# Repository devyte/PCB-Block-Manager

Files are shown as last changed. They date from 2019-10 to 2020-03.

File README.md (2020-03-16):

# Block Manager 
### Hardware Files For The Block Manager Board
These are the printed circuit board (PCB) files, CAD files, specification sheets and all technical drawings needed to make the DKblock Block Manager board. There are two boards that make a minimum DK system, a Block Manager PCB and a Pack Supervisor PCB (with software changes to the 20 client version provided). Note that the bill of materials (BOM) and other technical documents can be opened in [OpenOffice](https://www.openoffice.org) format and PCB files are in [EAGLE](https://www.autodesk.com/products/eagle/overview) format but they can also be opened and edited in the open source Kicad program.
One version is provided, that is Rev D which is a fully tested board.

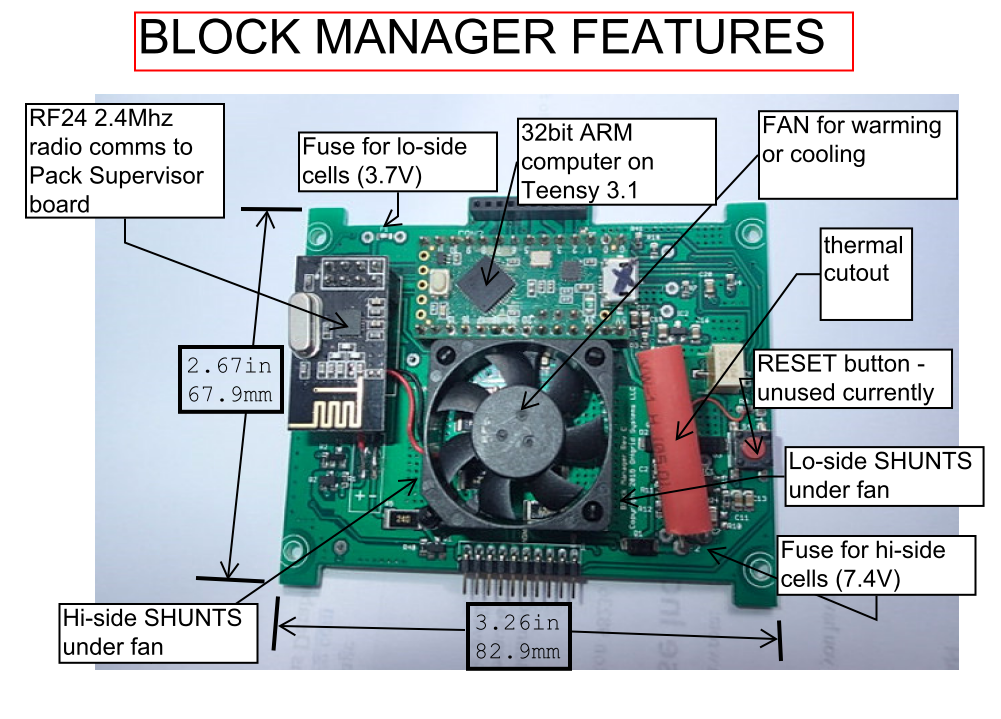
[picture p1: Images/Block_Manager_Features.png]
Block Manager Features


Block Manager Front RevD

Block Manager Back RevD

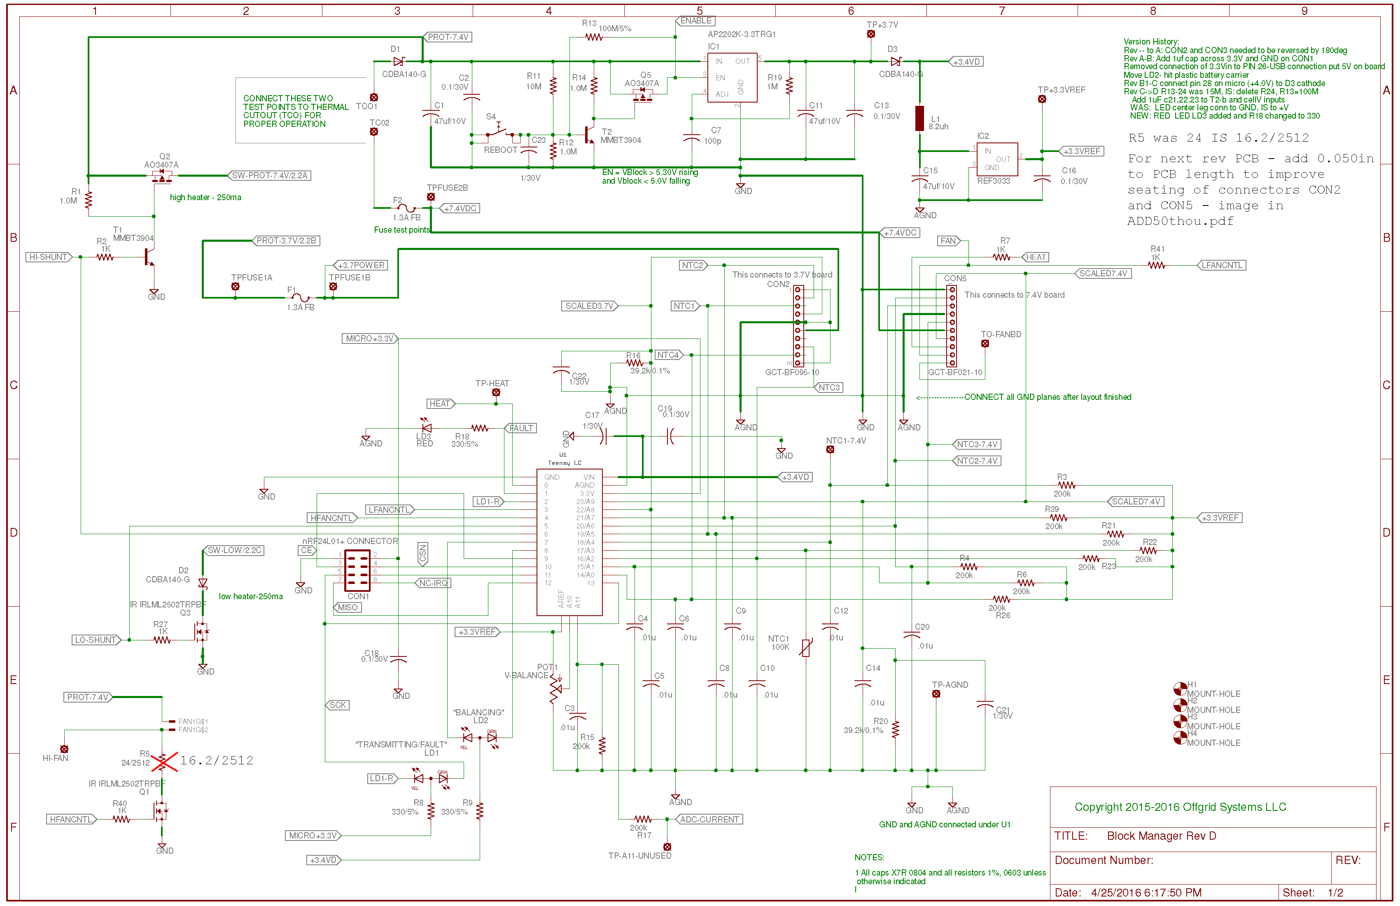
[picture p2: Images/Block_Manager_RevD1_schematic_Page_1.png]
Block Manager Schematic RevD1 Page 1


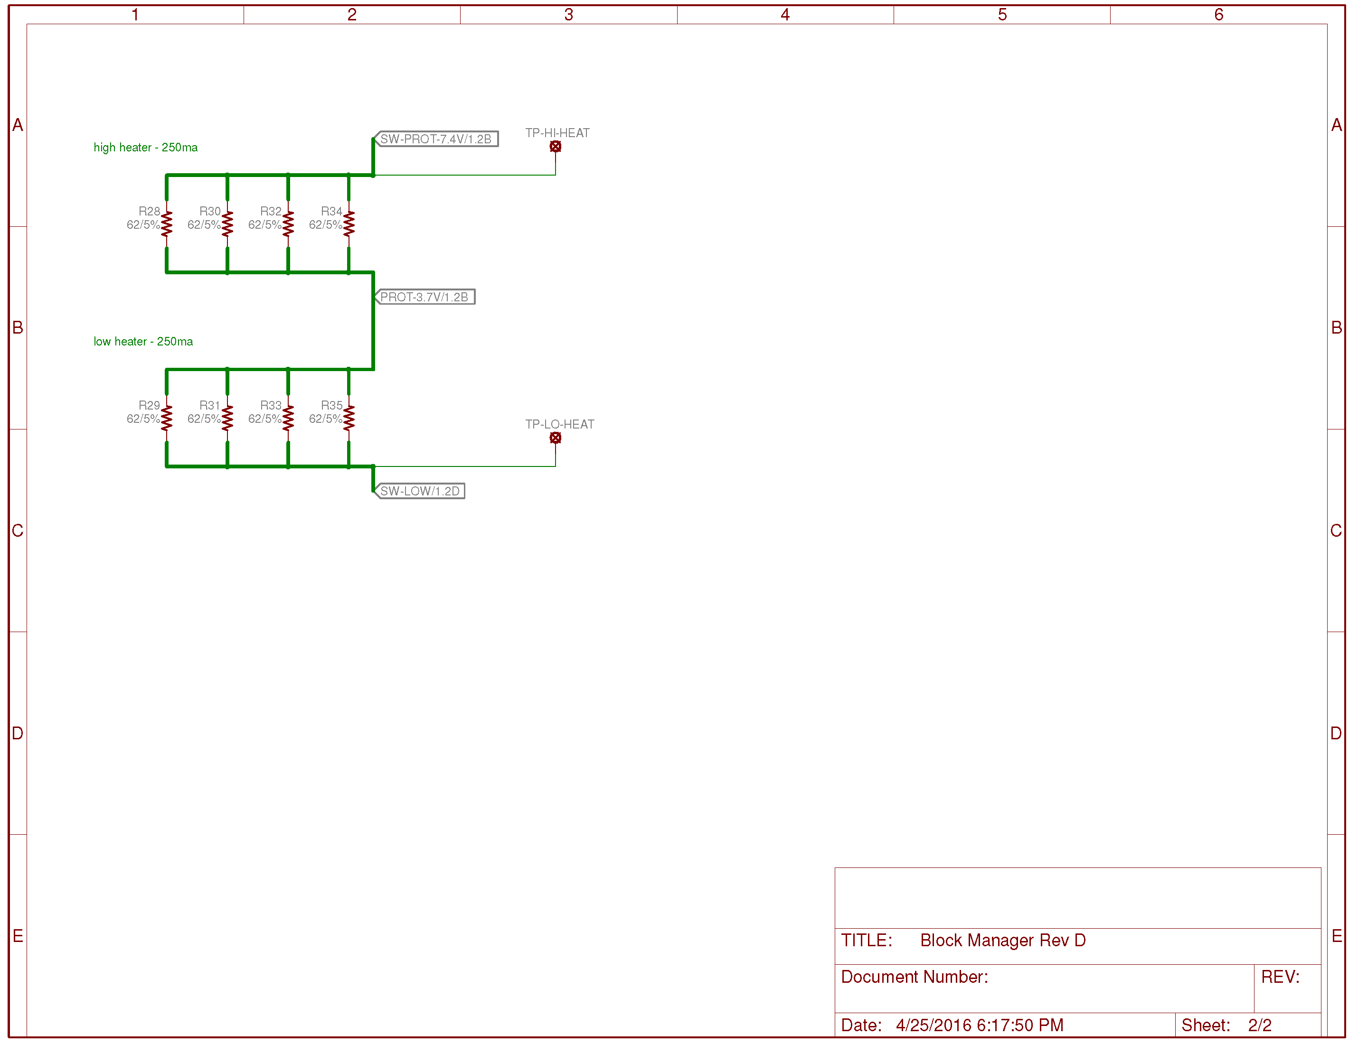
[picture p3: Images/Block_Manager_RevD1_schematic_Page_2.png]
Block Manager Schematic RevD1 Page 2


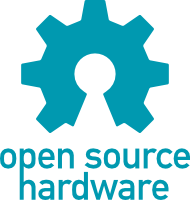
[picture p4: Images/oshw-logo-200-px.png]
Open Hardware


All DKblock software and hardware is released as open source hardware (OSHW) as defined by the OSHWA: https://www.oshwa.org/definition/ and under the JSON license defined at https://www.json.org/license.html

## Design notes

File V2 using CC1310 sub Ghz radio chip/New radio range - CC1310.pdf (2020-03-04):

Sheet1

Page 1

## New radio range – cc1310 using two CC1310 Lauchpads and TI SmartRF studio

Test conditions, Cow hill lab, TX/RX set at 50kbps, 2-GFSK, 25kHz deviation for most of testing, also tested at 500kBps,

### 175khz dev with no real changes, both CC1310 Lauchpad units had low cost PCB antenna

Freq (Mhz) TX power dBm RX @1 meter range(dBm) 9 meter range | notes
750 | 14 | -32 | -52 | all RX is at 0.0% PER and 0.00% Bit error rate and tested at 50k-500kBPS no discernable receive signal loss
850 -20
868 | | -20 | -49
950 -32
1000 | | -39 | -70 | Would go from -70 to -80 by just walking around room between TX and RX units
1100 -50
868 | -10 | | -72
868 OFF | | | -93

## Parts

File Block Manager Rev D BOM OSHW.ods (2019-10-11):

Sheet: Sheet1
Block Manager BOM |  | Last edited: | 10/10/19 | For building | Rev D PCB
Qty | Value | Device | Package | Parts | Description | 1KPRICE | 100PCPRICE | extended 1k | LOPROFILE-PINHEADER | LOPROFILE-SOCKET | MPN | Alternative PN |  | website
1 | LED | Red SMT LED | 0603 – side looking | LD3 | LED, 0603 RED clear 0603 RA SMD | 0.0488 | 0.112 | 0.0488 |  |  | Lite-On LTST-S270KRKT | Any RA Red 50mcd 0603 SMT LED
2 | LED | Yellow Green SMT LED | 3x2x1mm – side looking | LD2, LD1 | LED 3.0X1.0MM Y/G WTR CLR RA SMD | 0.10951 | 0.2 | 0.21902 |  |  | Kingbright APBA3010SYKCGKC-GX
10 | .01uf | C-USC0805 | TIMS_INDUCTOR_C0805 | C3, C4, C5, C6, C8, C9, C10, C12, c14, C20 | CAP CER 10000PF 50V 10% X7R 0805 | 0.008 | 0.015 | 0.08 |  |  | Kemet C0805C103K5RACTU
5 | 0.1uf | C-USC0805 | TIMS_INDUCTOR_C0805 | C2, C13, C16, C18, C19 | CAP CER 0.1UF 50V 10% X7R 0805 | 0.012 | 0.022 | 0.06 |  |  | Kemet C0805C104K5RACTU
4 | 1uf | USC0805 | C0805 | C17, C21, C22, C23 | CAP CER 1UF 50V 10% X7R 0805 | 0.08 | 0.14 | 0.32 |  |  | Kemet C0805C105K5RACTU
1 | 100p | C-USC0805 | TIMS_INDUCTOR_C0805 | C7 | CAP CER 100PF 50V 10% X7R 0805 | 0.048 | 0.08 | 0.048 |  |  | Kemet C0805C101K5RACTU
3 | 47uf/10V | C-USC0805K | C0805K | C11, C1, C15 | CAP CER 47UF 10V 20% X5R 0805 | 0.271 | 0.39 | 0.813 |  |  | Samsung CL21A476MRYNNNE | Murata GRM21BR61A476ME15L
2 | 1.3A FB | Fuse | F0603 | F1, F2 | FUSE BOARD MOUNT 1.3A 32VDC 0603 | 0.134 | 0.2 | 0.268 |  |  | TE 0603SFV125F/32-2
1 | 100K | NTC-MURATA-NCP18WF104J03RB | 603 | NTC1 | THERMISTOR NTC 100K OHM 5% 0603 | 0.07999 | 0.106 | 0.07999 |  |  | MURATA NCP18WF104J03RB
3 | 1.0M | R-US_R0603 | R0603 | R1, R12, R14 | RES SMD 1M OHM 1% 1/10W 0603 | 0.0084 | 0.0187 | 0.0252 |  |  | Bourns CR0603-FX-1004ELF
1 | 10M | R-US_R0603 | R0603 | R11 | RES SMD 10M OHM 5% 1/10W 0603 | 0.00525 | 0.0117 | 0.00525 |  |  | Bourns CR0603-JW-106ELF
1 | 100k pot | potentiometer | 7x7x7mm | POT1 | Potentiometer, 100k right angle, .5W SMD | 0.74 | 0.91 | 0.74 |  |  | Bourns 3361S-1-104GLF
5 | 1K | R-US_R0603 | R0603 | R2, R7, R27, R40, R41 | RES SMD 1K OHM 1% 1/10W 0603 | 0.0084 | 0.018 | 0.042 |  |  | Bourns CR0603-FX-1001ELF
1 | 100M | R-US_R0603 | R0603 | R13 | RES SMD 100M OHM 5% 1/10W 0603 | 0.0704 | 0.12 | 0.0704 |  |  | Stackpole HMC0603JT100M | any thick film 100M 5% resistor 0603
1 | 2.2M | R-US_R0603 | R0603 | R19 | RESISTOR, American symbol | 0.0041 | 0.1 | 0.0041 |  |  | Panasonic ERJ-3EKF2204V
10 | 200k | R-US_R0603 | R0603 | R3, R4, R6, R15, R17, R21, R22, R23, R26,R39 | RESISTOR, American symbol | 0.07 | 0.18 | 0.7 |  |  | Bourns CR0603-FX-2003ELF
1 | 24/2512 | R-US_R2512 | R2512 | R5 | RES SMD 24 OHM 5% 1W 2512 | 0.05 | 0.12 | 0.05 |  |  | Rohm MCR100JZHJ240
3 | 330/5% | R-US_R0603 | R0603 | R8. R9, R18 | RES SMD 330 OHM 5% 1/10W 0603 | 0.005 | 0.011 | 0.015 |  |  | Bourns CR0603-JW-331ELF
2 | 39.2K/ 0.1% | R-US_R0603 | R0603 | R16, R20 | RES SMD 39.2KOHM 0.1% 1/10W 0603 | 0.079 | 0.162 |  |  |  | Susumi RG1608P-3922-B-T5
8 | 62/5% | R-US_R2512 | R2512 | R28, R29, R30, R31, R32, R33, R34, R35 | RES SMD 62 OHM 5% 1W 2512 | 0.05 | 0.12 | 0.4 |  |  | Rohm MCR100JZHJ620
1 | 8.2uh | SM-1206 | SM-1206 | L1 | FIXED IND 8.2UH 25MA 800 MOHM | 0.1 | 0.136 | 0.1 |  |  | Abracon AIML-1206-8R2K-T
2 | AO3407A | AO3407A | SOT23-BIGPADS | Q2.Q5 | MOSFET P-CH 30V 4.3A SOT23 | 0.092 | 0.203 | 0.184 |  |  | Alpha AO3407A
1 | AP2202K-3.3TRG1 | MIC5205 | SOT23-5 | IC1 | VOLTAGE REGULATOR | 0.103 | 0.23 | 0.103 |  |  | Diodes AP2202K-3.3TRG1
1 | REF3033 | REF3033 | SOT23 | IC2 | IC VREF SERIES 3.3V SOT23-3 | 0.675 | 1.25 | 0.675 |  |  | TI REF3033AIDBZR
3 | CDBA140-G | CDBA140-G | DO214AC | D1, D2, D3 | DIODE SCHOTTKY 40V 1A DO214AC | 0.068 | 0.187 | 0.204 |  |  | Comchip CDBA140-G
2 | IRLML2502TRPBF | IRLML2060TRPBF | SOT23 | Q1, Q3 | MOSFET N-CH 60V 1.2A SOT23-3 | 0.11 | 0.144 | 0.22 |  |  | IR IRLML2502TRPBF
2 | MMBT3904 | MMBT3904LT1-NPN-SOT23-BEC | SOT23-BEC | T1, T2 | TRANS NPN 40V 0.2A SOT2 | 0.02 | 0.062 | 0.04 |  |  | NXP MMBT3904,215
1 | 10 pin socket | Female single inline socket | 1 row x 10 positions | CON2 | 2.0 mm socket, 10 pos, single row, gold, phosphor bronze | 0.634 | 0.772 | 0.634 |  |  | GCT BF085-10-A-0240-N-D | Sullins NPPN101BFCN-RC
1 | 10 pin header | Male single inline pin header | 1 row x 10 positions | CON5 | 2mm single row pin header 10 pin thru hole R/A (40pin) | 0.33 | 0.51 | 0.33 |  |  | Sullins NRPN401PARN-RC | GCT BF021-10-A-B-0400-0250-N
1 | tact switch | 6x6mm smt 4mm high |  | REBOOT | SWITCH TACTILE SPST-NO 0.05A 12V | 0.222 | 0.246 | 0.222 |  |  | PTS645SK43SMTR92 LFS
1 | nRF24L01+ | assembled PCB installed in PCB | 2X4 pins installs in CON1 | RF24 | Radio module RF, 2.4Mhz short range antenna built in | 0.5 |  | 0.6944444444 |  |  | Addicore nRF24L01+ | Addicore | Daughter board stuffed with 8 pin dip header and assembly soldered into board
1 | Teensy LC | Microcontroller module | 28 pin DIP (+3) | U1 | Teensy LC module pcb | $10.00 | $11.07 | $10.00 |  |  | Addicore Teensy LC | Addicore (for extra $0.10, Erin at Addicore will provide pins) |  |  | Daughter board stuffed with 8 pin dip header and assembly soldered into board
1 | PCB | Block Manager Rev D |  |  |  | 2 | 1 | $2.00 |  |  | Varies
 | FOLLOWING PARTS ARE ADDED @ POST ASSEMBLY ONLY! |  |  | FOLLOWING PARTS ARE ADDED @ POST ASSEMBLY ONLY! |  |  |  |  |  |  | FOLLOWING PARTS ARE ADDED @ POST ASSEMBLY ONLY!
1 | 30mm sq fan | 30X30MMFAN | 30x30mm | FAN1 | FAN AXIAL 30x30x7mm, 5V, 0.125in hole, 5cfm, 10k RPM, 30k hrs | 2 | 2 | 1 |  |  | Sunon |  |  | ebay
4 | Fir tree rivet | Barbed plastic fastener |  | Fan hardware | BARBED FASTENER 0.458" NYLON BLK | 0.03 |  | 0.12 |  |  | Essentra XT1250375A |  |  | http://us.essentracomponents.com/shop/en-US/essentracomponentsus/fir-tree-rivet--black--46-in-stem-length--344-in-head-dia--125-in-hole-dia-type-1-1097595
1 | 150C TCO | Thermal cutout | 10mm |  | Thermal cutout, 150C, snap action, one shot | 0.1 | 0.1 | 0.1 |  |  | TBD
 |  |  |  |  | Total cost |  |  | $20.57
 | ASSEMBLY INSTRUCTIONS
 | 1. LED placement with dome facing toward board edge

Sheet: Change log
10/22 – added new sullins femaile 10 pin socket NPPN101BFCN-RC

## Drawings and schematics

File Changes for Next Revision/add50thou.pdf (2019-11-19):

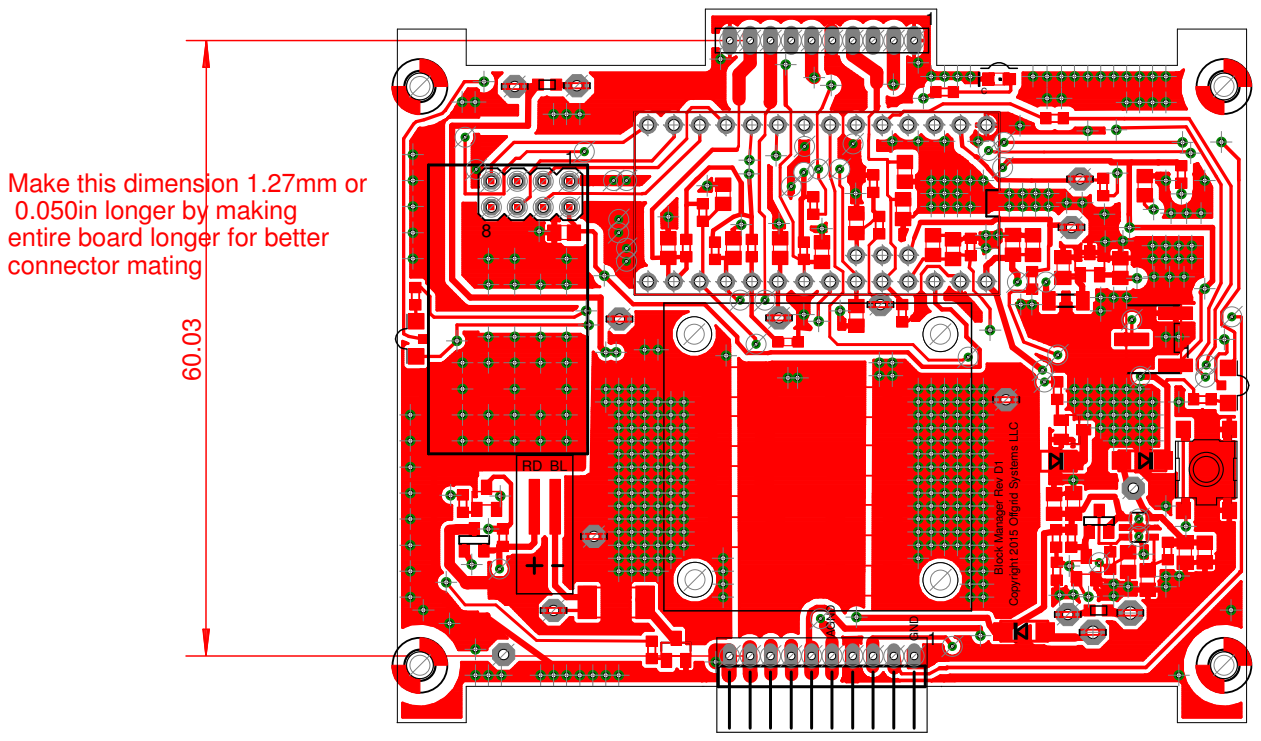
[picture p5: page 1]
AGND; GND

Make this dimension 1.27mm or
0.050in longer by making
entire board longer for better
connector mating

Copyright 2015 Offgrid Systems LLC

Block Manager Rev D1

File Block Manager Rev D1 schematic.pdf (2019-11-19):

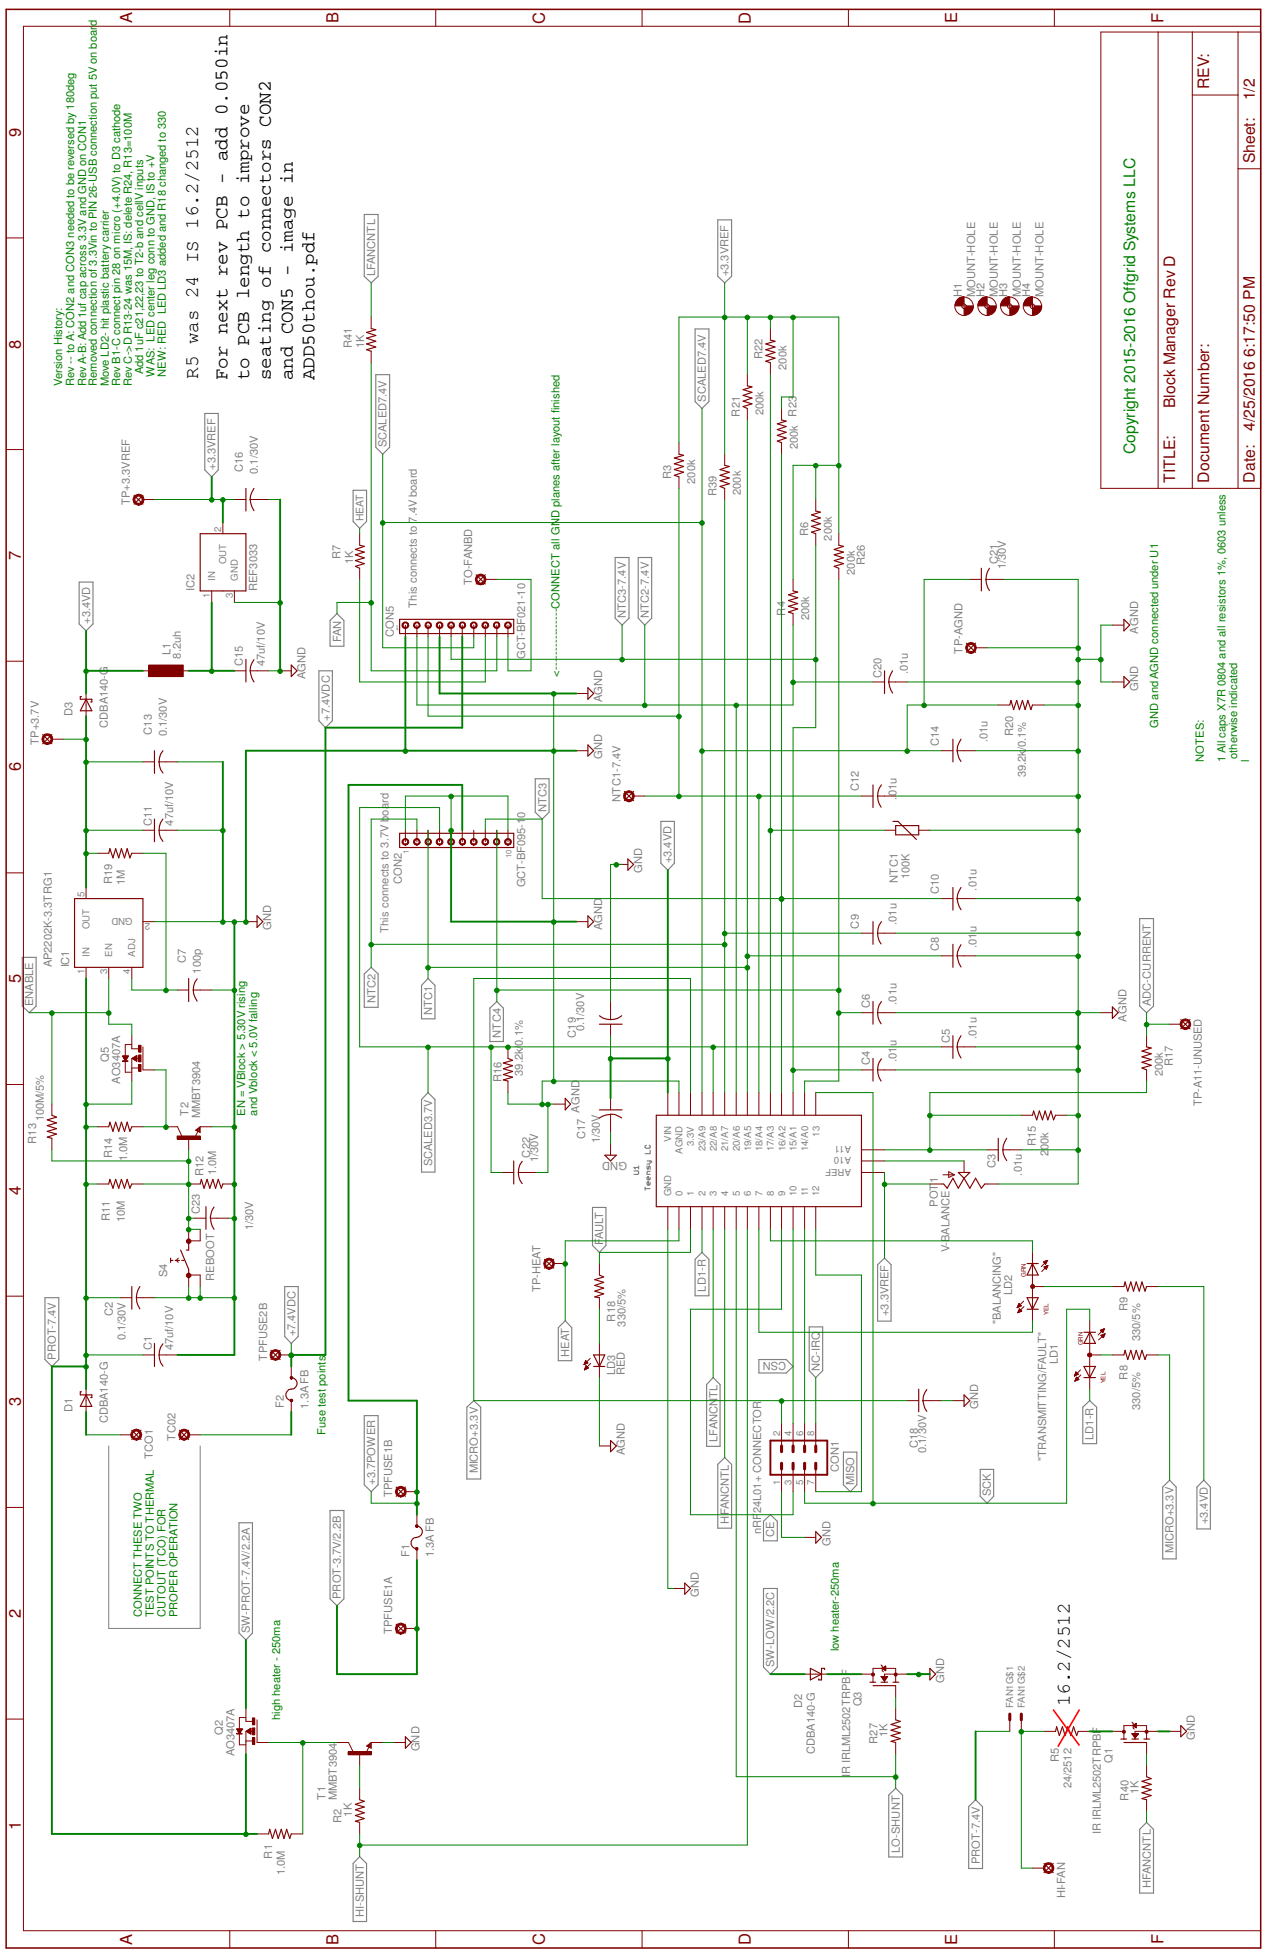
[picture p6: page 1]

Removed connection of 3.3Vin to PIN 26-USB connection put 5V on board

Rev -- to A: CON2 and CON3 needed to be reversed by 180deg

Rev B1-C connect pin 28 on micro (+4.0V) to D3 cathode

Rev A-B: Add 1uf cap across 3.3V and GND on CON1

Rev C->D R13-24 was 15M, IS: delete R24, R13=100M

NEW: RED LED LD3 added and R18 changed to 330

WAS: LED center leg conn to GND, IS to +V

Copyright 2015-2016 Offgrid Systems LLC

Add 1uF c21,22,23 to T2-b and cellV inputs

Move LD2- hit plastic battery carrier

<----------------CONNECT all GND planes after layout finished

This connects to 7.4V board

1 All caps X7R 0804 and all resistors 1%, 0603 unless

GND and AGND connected under U1

This connects to 3.7V board

TEST POINTS TO THERMAL

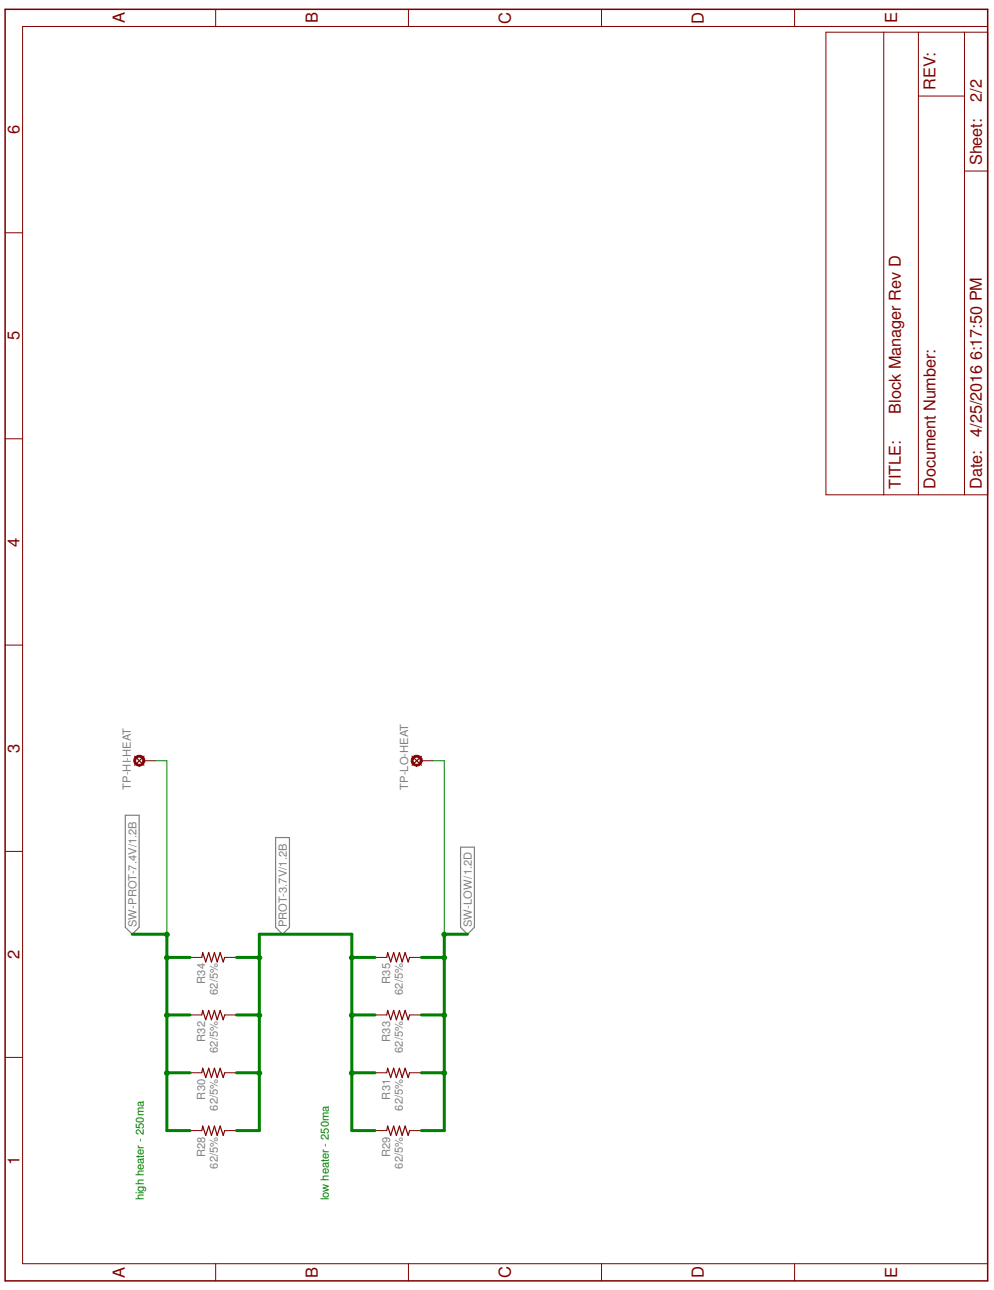
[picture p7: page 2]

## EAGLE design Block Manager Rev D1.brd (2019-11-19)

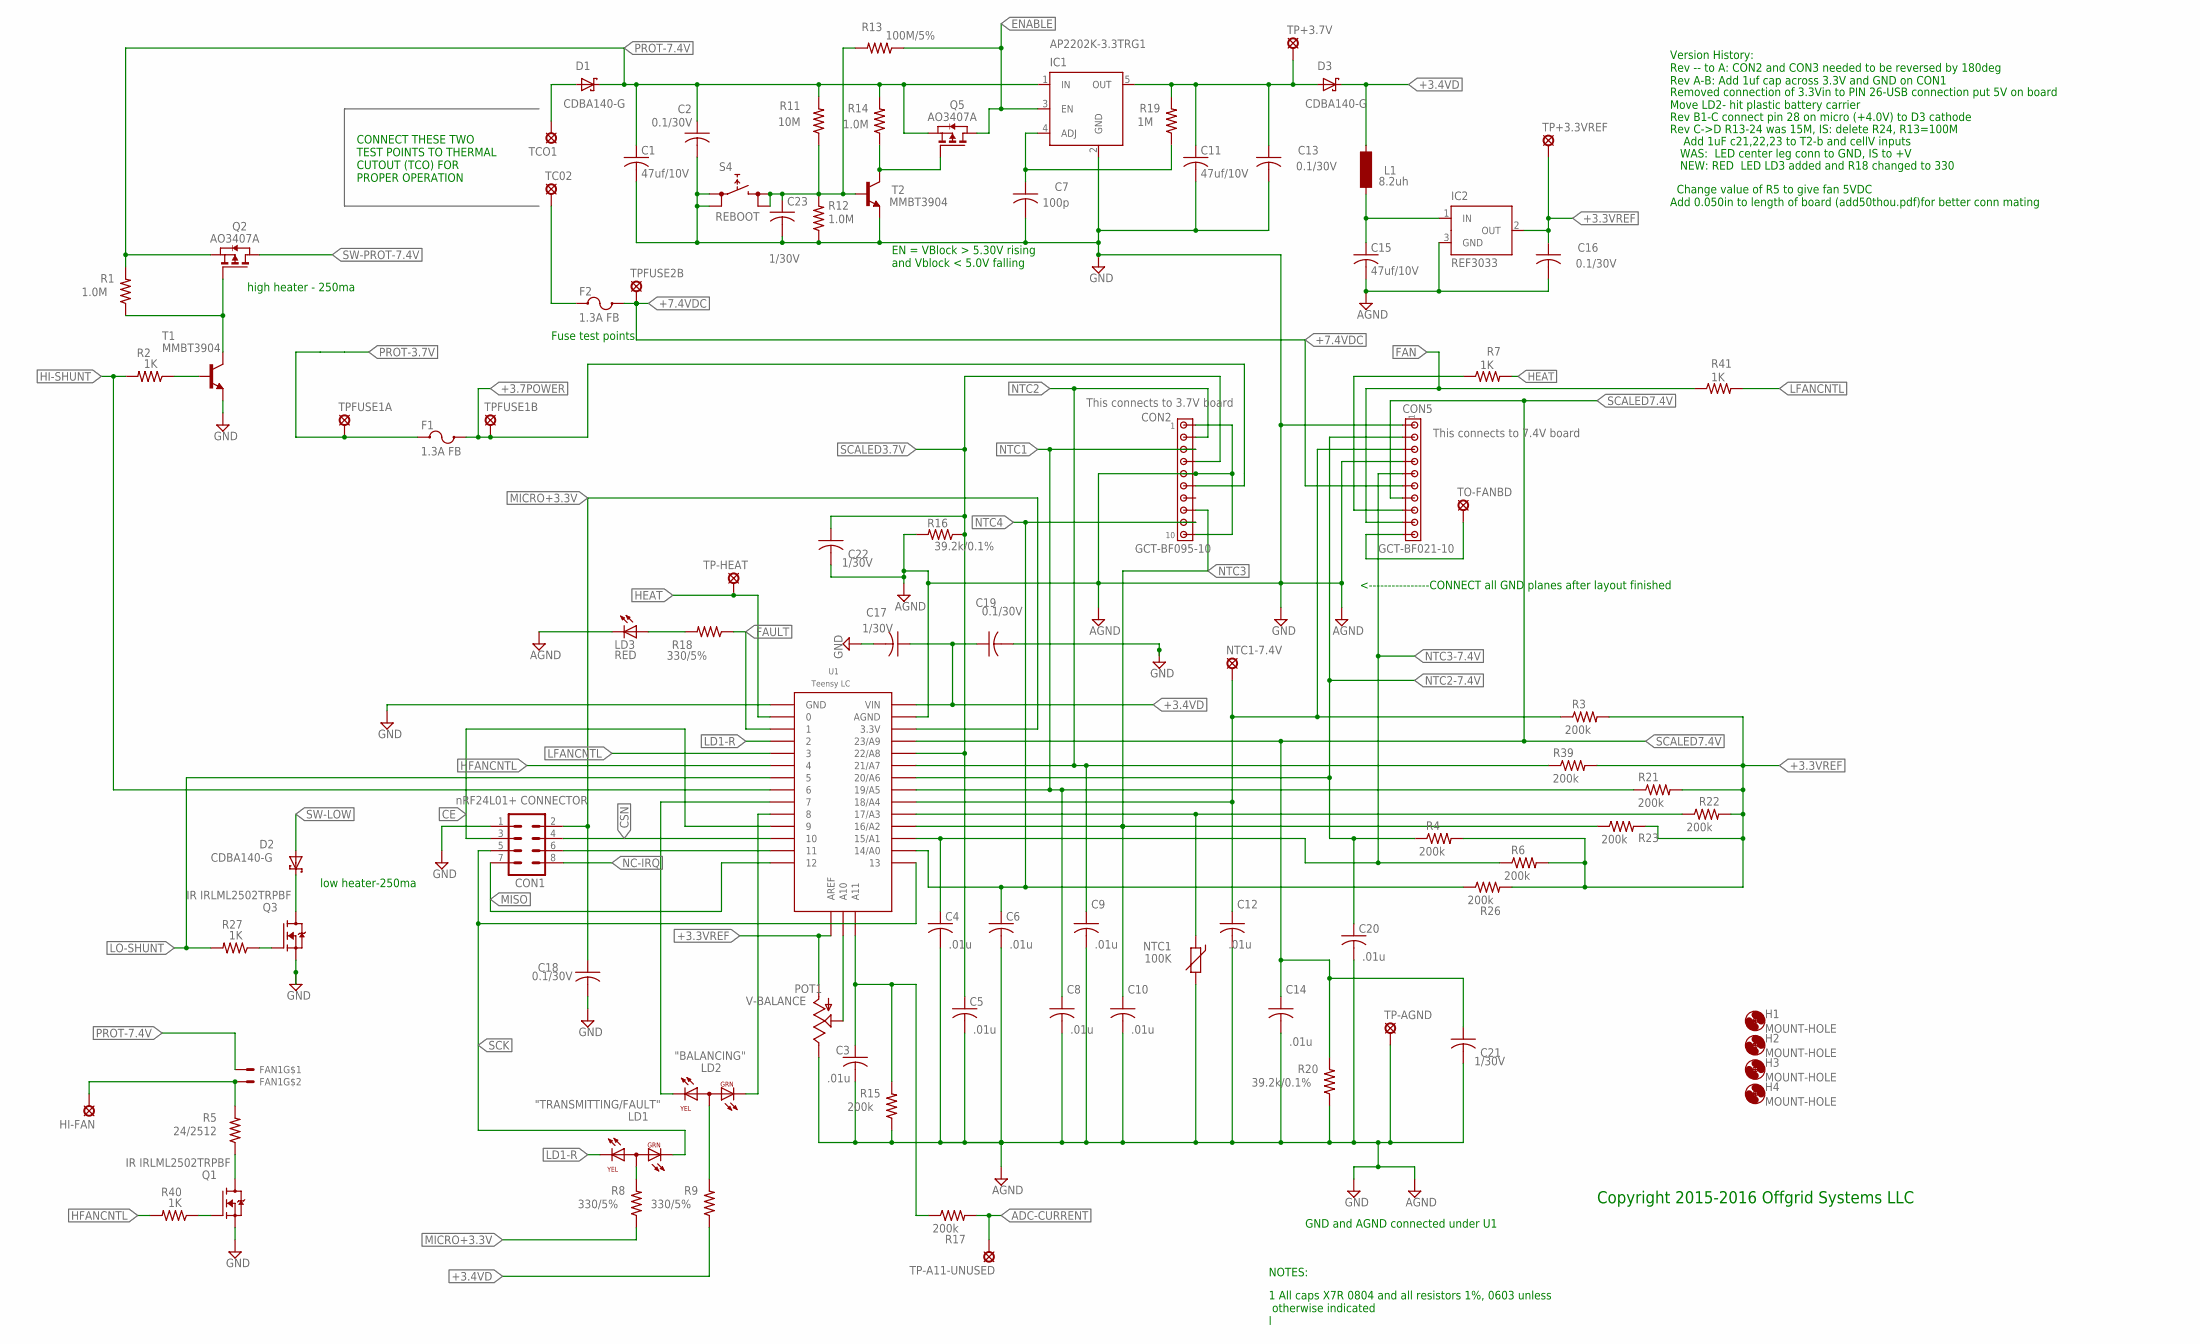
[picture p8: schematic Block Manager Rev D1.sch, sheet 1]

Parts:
C1, C11, C15: 47uf/10V; C0805K; MPN Murata GRM21BR61A476ME15L
C2, C13, C16: 0.1/30V; TIMS_INDUCTOR_C0805; MPN Kemet C0805C104K5RACTU
C3, C4, C5, C6, C8, C9, C10, C12, C14, C20: .01u; TIMS_INDUCTOR_C0805; MPN Kemet C0805C103K5RACTU
C7: 100p; TIMS_INDUCTOR_C0805; MPN Kemet C0805C104K5RACTU
C17, C21, C22, C23: 1/30V; TIMS_INDUCTOR_C0805; MPN Kemet C0805C104K5RACTU
C18, C19: 0.1/30V; TIMS_INDUCTOR_C0805; MPN Kemet C0805C103K5RACTU
CON1: nRF24L01+ CONNECTOR; MA04-2; MPN Precidip 803-87-008-10-012101
CON2: GCT-BF095-10; GCT-BF085-10
CON5: GCT-BF021-10
D1, D2, D3: CDBA140-G; DO214AC; MPN comchip CDBA140-G
F1: 1.3A FB; TE-0603SFV125F; MPN TE 0603SFV125F/32-2
F2: 1.3A FB; TE-0603SFV125F; MPN TE 0603SFV125F
FAN1: 30mm fan; 30X30MMFAN; MPN-FAN TBD
H1, H2, H3, H4: MOUNT-HOLE; 2,6
HI-FAN: LSP10
IC1: AP2202K-3.3TRG1; SOT23-5; MPN Diodes AP2202K-3.3TRG1
IC2: REF3033; SOT23; MPN TI REF3033AIDBZR
L1: 8.2uh; SM-1206; MPN Abracon AIML-1206-8R2K-T
LD1: "TRANSMITTING/FAULT"; SUN-XZMDKVG56W; MPN Kingbright APBA3010SYKCGKC-GX
LD2: "BALANCING"; SUN-XZMDKVG56W; MPN Kingbright APBA3010SYKCGKC-GX
LD3: RED; LITEON-LTST-S270KRKT; MPN LITEON-LTST-S270KRKT
NTC1: 100K; 0603; MPN MURATA NCP18WF104J03RB
NTC1-7.4V: LSP10
POT1: V-BALANCE; BOURNS-3361-RA; MPN Bourns 3361S-1-104GLF
Q1, Q3: IRLML2502TRPBF; SOT23; MPN IR IRLML2502TRPBF
Q2: AO3407A; SOT23-BIGPADS; MPN Alpha AO3407A
Q5: AO3407A; SOT23-BIGPADS
R1, R12, R14: 1.0M; R0603; MPN Bourns CR0603-FX-1004ELF
R2, R7, R27, R40, R41: 1K; R0603; MPN Bourns CR0603-FX-1001ELF
R3, R4, R6, R15, R17, R21, R22, R23, R26, R39: 200k; R0603; MPN Bourns CR0603-FX-2003ELF
R5: 24/2512; R2512; MPN Rohm MCR100JZHJ240
R8, R9: 330/5%; R0603; MPN Bourns CR0603-JW-331ELF
R11: 10M; R0603; MPN Bourns CR0603-JW-106ELF
R13: 100M/5%; R0603; MPN Stackpole HMC0603JT100M
R16, R20: 39.2k/0.1%; R0603; MPN Susumu RG1608P-3922-B-T5
R18: 330/5%; R0603; MPN Bourns CR0603-FX-2003ELF
R19: 1M; R0603; MPN Bourns CR0603-FX-1004ELF
S4: REBOOT; PTS645; MPN C&k PTS645SM43SMTR92 LFS
T1, T2: MMBT3904; SOT23-BEC; MPN NXP MMBT3904,215
TC02: SOLPAD1.2MMDRILL; SOLPADWITH1.2MMDRILL
TCO1: SOLPAD1.2MMDRILL; SOLPADWITH1.2MMDRILL
TO-FANBD: LSP10
TP+3.3VREF, TP+3.7V: LSP10
TP-A11-UNUSED: LSP10
TP-AGND: LSP10
TP-HEAT: LSP10
TPFUSE1A, TPFUSE1B, TPFUSE2B: LSP10
U1: Teensy LC; TEENSY_3.0-DIP+ANALOG; MPN OshPark Teensy 3.1

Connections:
4VREFIN: C15.1, IC2.1 (IN), L1.1
+3.3VREF: C16.1, IC2.2 (OUT), POT1.1 (A), R3.2, R4.2, R6.2, R21.2, R22.2, R23.2, R26.2, R39.2, TP+3.3VREF.MP, U1.AREF
+3.4VD: C17.1, C19.1, D3.C, L1.2, R9.1, U1.VIN
+3.7POWER: CON2.P$6 (6), F1.P$2 (2A), TPFUSE1B.MP
+4.5V: C11.1, C13.1, D3.A, IC1.5 (OUT), R19.2, TP+3.7V.MP
+7.4VDC: CON5.P$6 (6), F2.P$2 (2A), TPFUSE2B.MP
ADC-CURRENT: R17.2, TP-A11-UNUSED.MP
ADS: D2.C, Q3.3 (D)
CE: CON1.3, U1.9
CSN: CON1.4, U1.10
ENABLE: IC1.3 (EN), Q5.2 (D), R13.1
FAN: CON5.P$9 (9), R41.1
FAULT: R18.1, U1.1
GND: C1.2, C2.2, C3.2, C4.2, C5.2, C6.2, C7.2, C8.2, C9.2, C10.2, C11.2, C12.2, C13.2, C14.2, C15.2, C16.2, C17.2, C18.2, C19.2, C20.2, C21.2, C22.2, C23.2, CON1.1, CON2.P$1 (1), CON2.P$5 (5), CON2.P$10 (10), CON5.P$1 (1), CON5.P$4 (4), IC1.2 (GND), IC2.3 (GND), LD3.CATHODE (C), NTC1.2, POT1.3 (E), Q1.2 (S), Q3.2 (S), R12.1, R15.1, R16.2, R20.1, S4.1, S4.2, T1.E, T2.E, TP-AGND.MP, U1.AGND, U1.GND
HEAT: R7.2, TP-HEAT.MP, U1.0
HEATER: CON5.P$8 (8), R7.1
HFANCNTL: R40.2, U1.4
HI-SHUNT: R2.2, U1.6
LD1-R: LD1.2-CATH-RED (CR), U1.2
LFANCNTL: R41.2, U1.3
LO-SHUNT: R27.2, U1.5
MICRO+3.3V: C18.1, CON1.2, R8.1, U1.3.3V
MISO: CON1.7, U1.12
MOSI: CON1.6, U1.11
unnamed: LD3.ANODE (A), R18.2
unnamed: D1.A, TCO1.MP
unnamed: NTC1.1, R22.1, U1.17/A3
unnamed: Q2.1 (G), R1.1, T1.C
unnamed: Q1.3 (D), R5.1
unnamed: LD2.3-CATH-GRN (CG), U1.8
unnamed: LD2.2-CATH-RED (CR), U1.7
unnamed: LD1.1-ANODE (A), R8.2
unnamed: F2.P$1 (1A), TC02.MP
unnamed: Q1.1 (G), R40.1
unnamed: Q3.1 (G), R27.1
unnamed: C23.1, R11.1, R12.2, R13.2, S4.3, S4.4, T2.B
unnamed: C7.1, IC1.4 (ADJ), R19.1
unnamed: Q5.1 (G), R14.1, T2.C
unnamed: R2.1, T1.B
unnamed: FAN1.2, HI-FAN.MP, R5.2
NC-IRQ: CON1.8
NTC1: C8.1, CON2.P$3 (3), R21.1, U1.19/A5
NTC1-7.4V: C12.1, CON5.P$3 (3), NTC1-7.4V.MP, R3.1, U1.18/A4
NTC2: C9.1, CON2.P$2 (2), R39.1, U1.21/A7
NTC2-7.4V: C20.1, CON5.P$2 (2), R4.1, U1.20/A6
NTC3: C10.1, CON2.P$8 (8), R23.1, U1.16/A2
NTC3-7.4V: C4.1, CON5.P$5 (5), R6.1, U1.15/A1
NTC4: C6.1, CON2.P$9 (9), R26.1, U1.14/A0
OPENFANBD-PIN: CON5.P$10 (10), TO-FANBD.MP
PROT-3.7V: F1.P$1 (1A), TPFUSE1A.MP; also elsewhere on the board
PROT-7.4V: C1.1, C2.1, D1.C, FAN1.1, IC1.1 (IN), Q2.3 (S), Q5.3 (S), R1.2, R11.2, R14.2
SCALED3.7V: C5.1, C22.1, CON2.P$4 (4), R16.1, U1.22/A8
SCALED7.4V: C14.1, C21.1, CON5.P$7 (7), R20.2, U1.23/A9
SCK: CON1.5, LD1.3-CATH-GRN (CG), U1.13
SW-LOW: D2.A; also elsewhere on the board
SW-PROT-7.4V: Q2.2 (D); also elsewhere on the board
T: LD2.1-ANODE (A), R9.2
UNUSED-ADC: C3.1, R15.2, R17.1, U1.A11
VBALANCE: POT1.2 (S), U1.A10

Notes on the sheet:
Copyright 2015-2016 Offgrid Systems LLC
GND and AGND connected under U1
NOTES:
1 All caps X7R 0804 and all resistors 1%, 0603 unless otherwise indicated l
Version History: Rev -- to A: CON2 and CON3 needed to be reversed by 180deg Rev A-B: Add 1uf cap across 3.3V and GND on CON1
low heater-250ma
Fuse test points
high heater - 250ma
EN = VBlock > 5.30V rising and Vblock < 5.0V falling
This connects to 3.7V board
<----------------CONNECT all GND planes after layout finished
This connects to 7.4V board
Removed connection of 3.3Vin to PIN 26-USB connection put 5V on board Move LD2- hit plastic battery carrier
CONNECT THESE TWO TEST POINTS TO THERMAL CUTOUT (TCO) FOR PROPER OPERATION
Rev B1-C connect pin 28 on micro (+4.0V) to D3 cathode
Rev C->D R13-24 was 15M, IS: delete R24, R13=100M
Add 1uF c21,22,23 to T2-b and cellV inputs
WAS: LED center leg conn to GND, IS to +V
NEW: RED LED LD3 added and R18 changed to 330
Change value of R5 to give fan 5VDC Add 0.050in to length of board (add50thou.pdf)for better conn mating

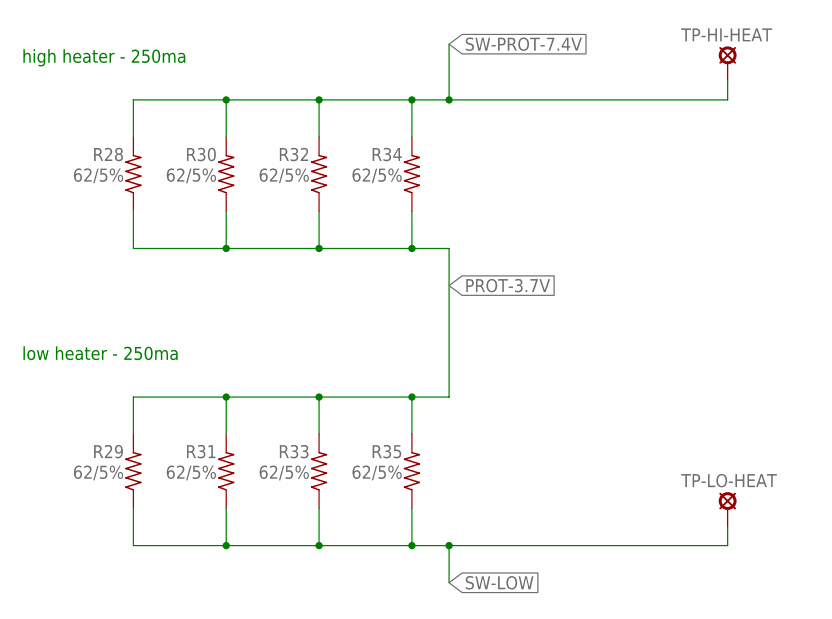
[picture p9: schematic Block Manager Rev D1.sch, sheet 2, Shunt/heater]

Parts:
R28, R29, R30, R31, R32, R33, R34, R35: 62/5%; R2512; MPN Rohm MCR100JZHJ620
TP-HI-HEAT: LSP10
TP-LO-HEAT: LSP10

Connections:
PROT-3.7V: R28.1, R29.2, R30.1, R31.2, R32.1, R33.2, R34.1, R35.2; also elsewhere on the board
SW-LOW: R29.1, R31.1, R33.1, R35.1, TP-LO-HEAT.MP; also elsewhere on the board
SW-PROT-7.4V: R28.2, R30.2, R32.2, R34.2, TP-HI-HEAT.MP; also elsewhere on the board

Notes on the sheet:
high heater - 250ma
low heater - 250ma

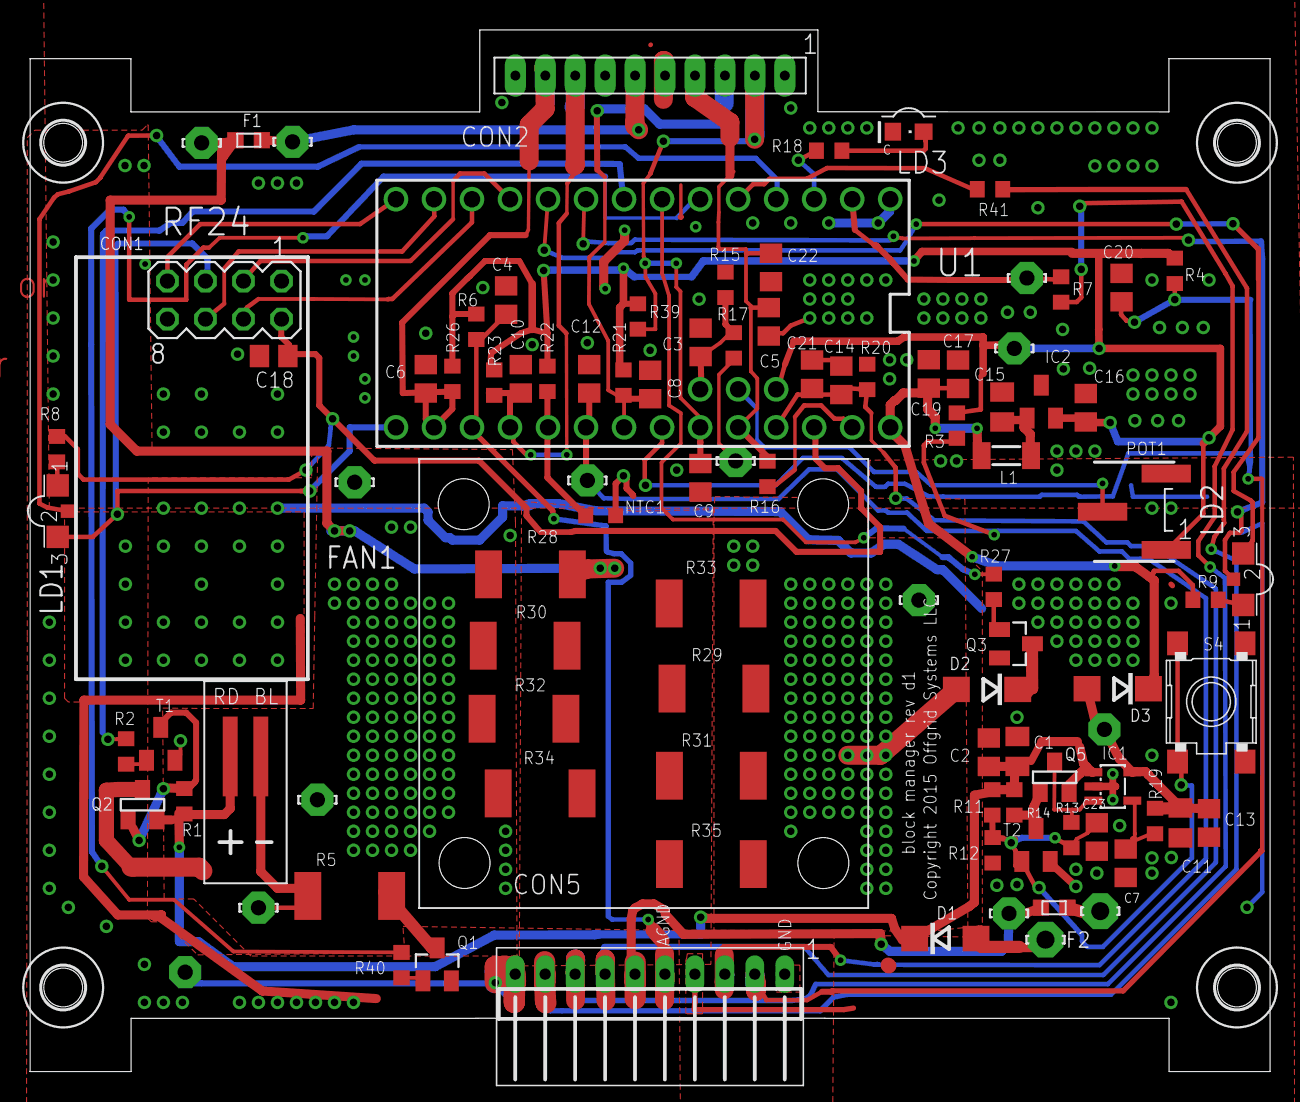
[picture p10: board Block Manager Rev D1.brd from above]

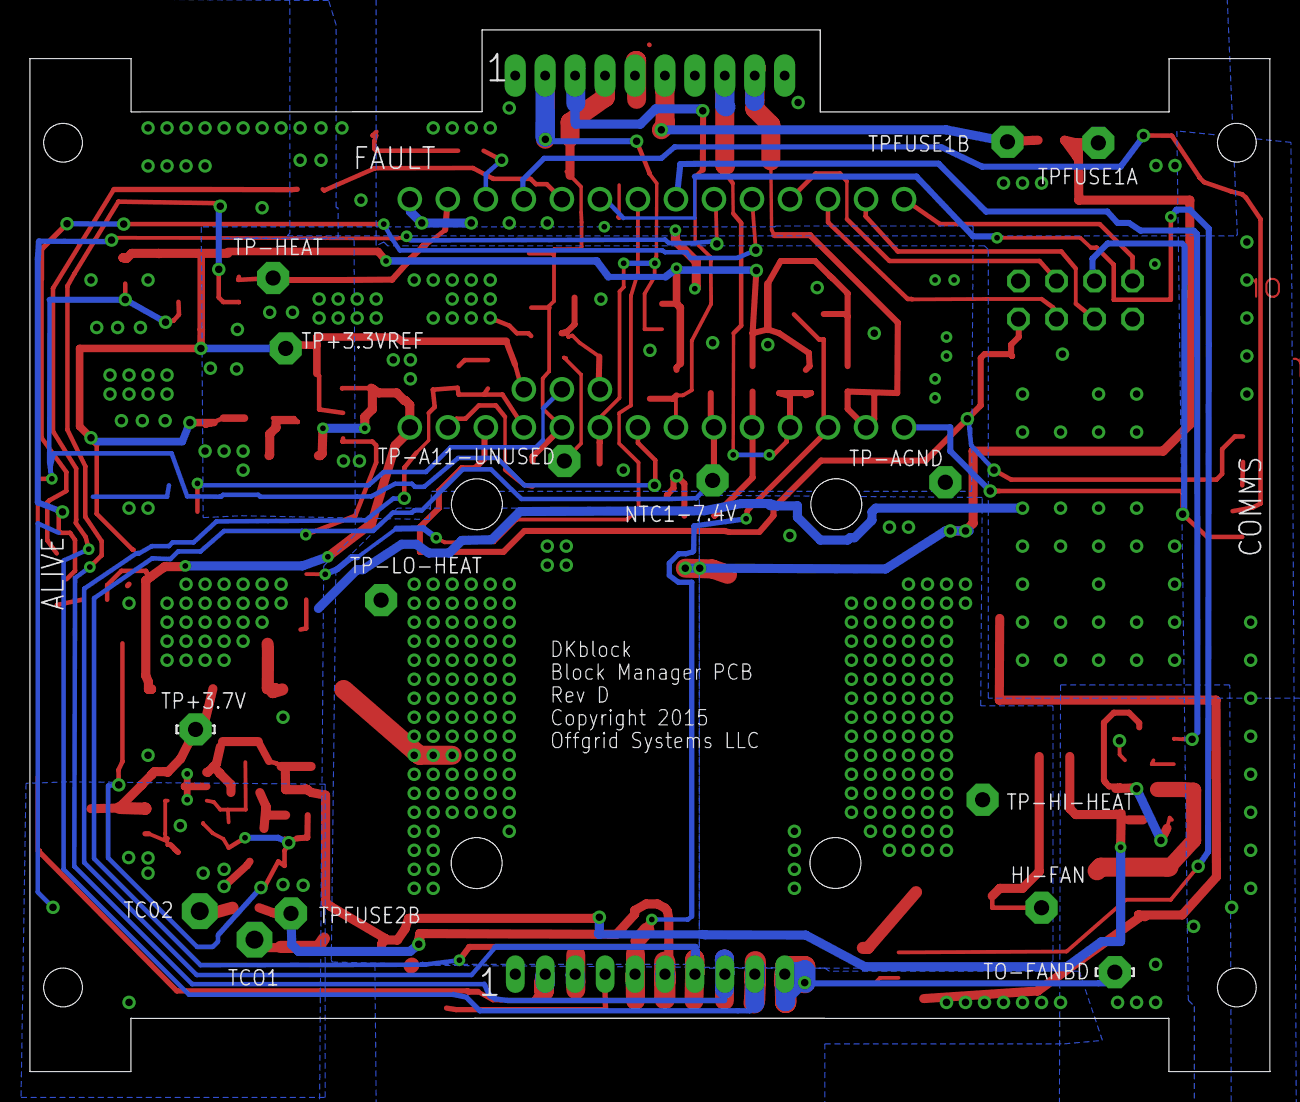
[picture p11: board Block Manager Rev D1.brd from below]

Board: 2 copper layers, 82.8 x 69.6 mm, 103 parts (2 on the bottom side), 58 nets.

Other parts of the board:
DRILEGEND: DRILEGEND

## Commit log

2019-11-19 PCB layout in Eagle
2019-11-19 Eagle schematic for Block Manager
    [Block Manager Rev D1.sch]
2019-11-19 Eagle board layout for Block Manager
    [Block Manager Rev D1.brd]
2019-11-19 For next board, use to extend board
2019-11-19 Picture of board and functions
2019-11-19 add picture of board
2020-03-16 Kicad update
